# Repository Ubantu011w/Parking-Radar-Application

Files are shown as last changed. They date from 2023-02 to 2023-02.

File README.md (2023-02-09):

# **Parking radar sensor**
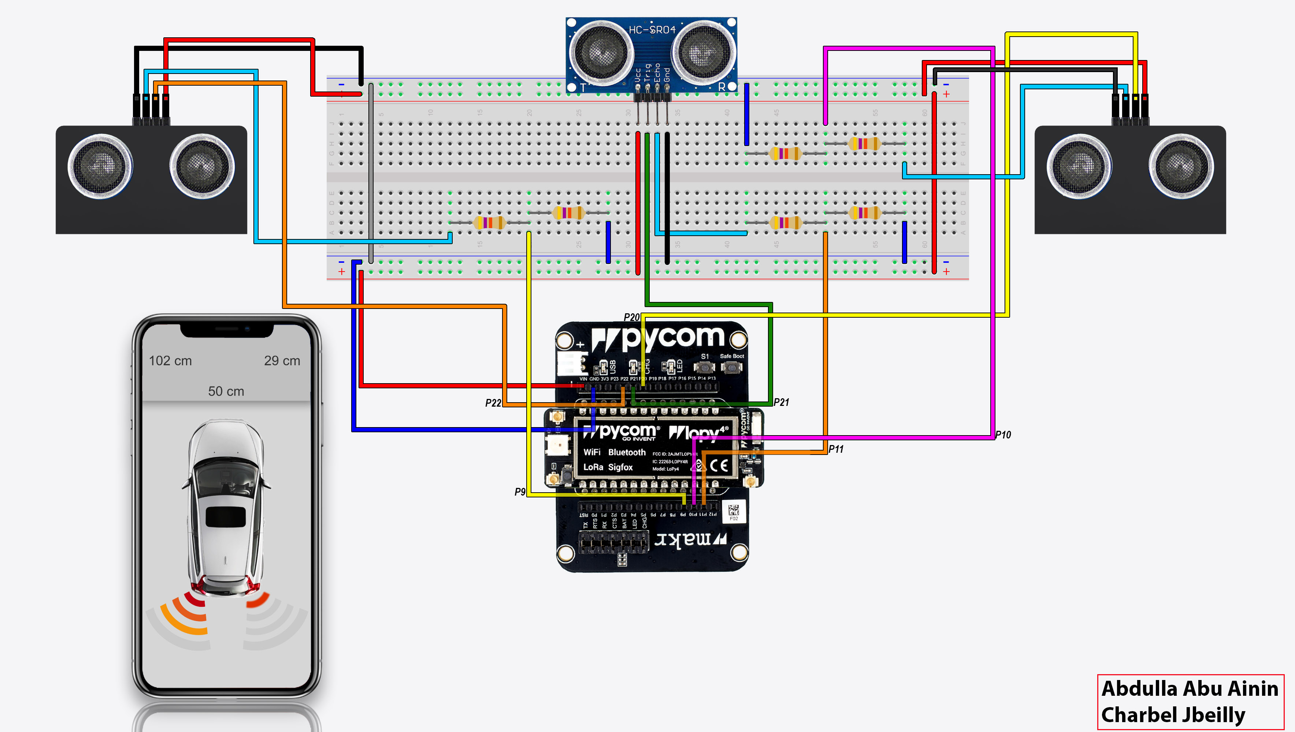
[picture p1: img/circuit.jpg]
Project


* Ladda ner Appen: 
    * Android [Prototype.apk](https://drive.google.com/file/d/1J4INymdXIyaqrTZJNHQ8nDmvR2BSV0AG/view?usp=sharing) 17 MB
    * Windows [Prototype.zip](https://drive.google.com/file/d/10sR1H_vFRUNZAB479mF9K6l9i8I3TnrY/view?usp=sharing) 20 MB

- Bilder [/img](./img/)

# Beskrivning och Bakgrund:
Parking Radar Sensor med Arduino som kommunicerar med en app på android, Radarn är baserad på 3 ultraljud sensorer som upptäcker hinder från 3 olika håll; vänster, höger och mitten.
 Vi har tänkt att sensorerna ska bli ett säkerhetssystem som varnar användaren för kommande hinder. Sensorerna är främst tänkte för bilar. Så att bilen har ett extra skydd som varnar om nära objek/hinder så att man inte ska krocka. Vi bestämde oss för detta projekt för vi tyckte det lät intressant samt en utmaning att ha med tre sensorer istället för en. Vi ska även försvåra arbetet med att göra en applikation som visar värderna från sensorerna. Men allt kommer vara värt det i slutändan.

# Abstract:
Vi började med att bestämma vad vi skulle göra. Vi hade möte med Morgan och fick klartecken att börja jobba. Vi beställde då delar och träffades i biblioteket för att diskutera hur vi skulle gå till väga. Vi jobbade med att konstruera en app som tar emot värden från en mqtt server som tar emot sina värden från kopplingen vi gjorde med tre stycken ultraljud sensorer. Vi använde oss av adafruit för att öppna mqtt server. För appen användes unity och vs code. Och för att få fram current time använde vi atom. Efter varje pass vi arbetade dokumenterade vi i [timelog.md](./doc/timelog.md) vad vi gjorde och hur länge vi jobbade. Vi fortsatte att ha möten med Morgan och fick feedback samt vi diskuterade våra idéer. Slutligen fick vi allting och blir klart. Vi har en fungerande app som tar emot värden från mqtt som tar emot sina värden från våran koppling. Detta är tänkt att fungera som en bilsesnor för att varna användaren om avståndet till objekt/hinder som finns bakom bilen.

# Resultat:
Resultatet blev en app på android som visar värden från  (Parkerings sensorerna) via Mqtt Broker.

## Projektet:

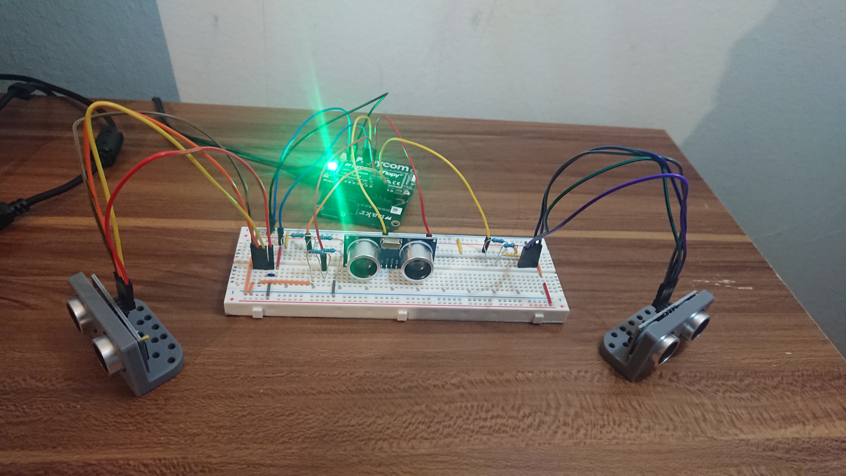
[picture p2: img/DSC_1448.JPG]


## Appen:

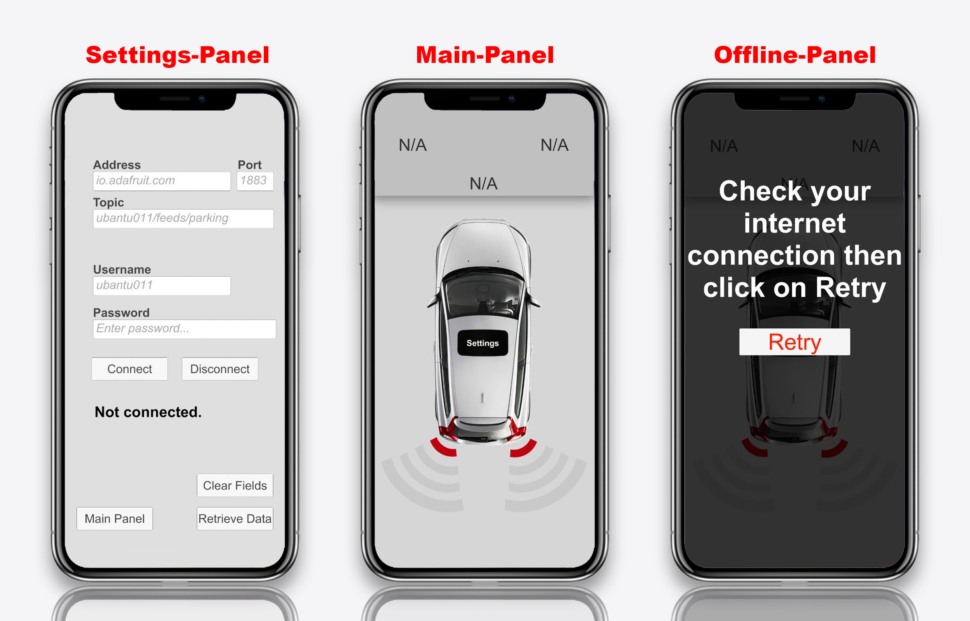
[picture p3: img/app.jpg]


* [/src](./src/)
    * [Project_files](./src/project_files)
    * [App_files](./src/App_files)
---

# Metod:
Filerna med beskrivning:
* [/doc](./doc/)
    * [Hardware.md](./doc/hardware.md)
    * [Setup.md](./doc/setup.md)
    * [Test.md](./doc/test.md)
## Andra filer:
* [/doc](./doc/)
    * [Requirments.md](./doc/requirments.md)
    * [Timelog.md](./doc/timelog.md)
    * [3d Model - Sensor-hållare](./doc/3d_modell)

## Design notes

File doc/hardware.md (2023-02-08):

# Sammanfattning:
Den första sensorn kopplas direkt på breadboard och sladdar dras från pycom till breadboarden så att sensorn får ström. De andra två sensorerna kopplas inte fast i breadboarden utan är mer rörliga så att de går att justera. De två lösa sensorerna kopplas via hon-kablar. Till varje sensor behöver vi 2 resistorer. Och alla är kopplade till GND och VIN. (Kan behövas bild på kopplingen)

## Vi behöver följande:

| st | Item's name | Link |
|----|:---:|:---:|
| 3  | HC-SR04 | [m.nu](https://www.m.nu/sensorer-matinstrument/hc-sr04-ultrasonic-sensor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) |
| 1  | Pycom lopy 4 | [m.nu](https://www.m.nu/pycom/lopy4-with-headers) |
| 1  | Expansion Board 3.1 | [m.nu ](https://www.m.nu/pycom/expansion-board-31)  |
|  3,3  | 1k , 2.2k Resistors | [Amazon.de](https://www.amazon.de/-/en/gp/product/B01M7N4WB6/ref=ppx_yo_dt_b_asin_title_o00_s00?ie=UTF8&psc=1) |
| 1  | breadboard & wiring kit | [Amazon.de](https://www.amazon.de/-/en/gp/product/B01M7N4WB6/ref=ppx_yo_dt_b_asin_title_o00_s00?ie=UTF8&psc=1) |

I HC-SR04 sensorn har vi 4 pins (VCC,TRIG,ECHO,GND). Dessa sensorer behöver 5v så vi kommer att använda VIN pin från Pycom enheten för att använda sensorerna, samtidigt behöver vi minska voltage från 5V till 3,3 för att kunna ansluta den till ECHO då kan vi använda 1 st 1k resistor och 1 st 2.2k resistor för varje sensor.

- Vi börjar först med att koppla lopy4 på expansion boardet:

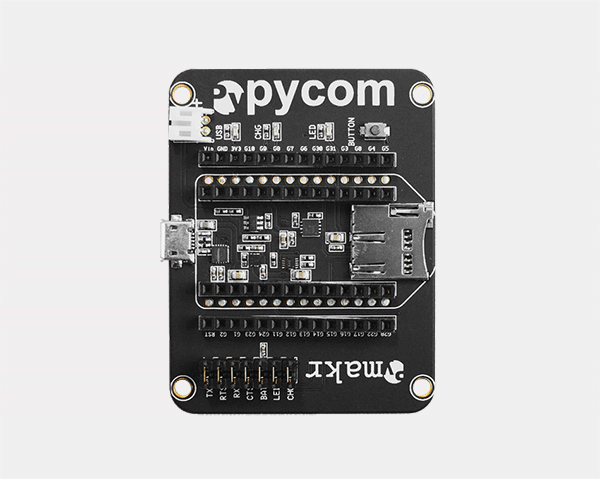
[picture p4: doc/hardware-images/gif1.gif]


- Sen kopplas 1 st 1k resistor och 1 st 2k resistorer i breadboarden och ena sensorn kopplas och ansluts till Pycom på följande sätt: ("s1" för första sensorn)
  - LoPy4 VIN <--> s1.VCC
  - LoPy4 P21 <--> s1.TRIG
  - s1.ECHO <--> 2.2k resistor <--> 1k resistor <--> LoPy4 P11
  - LoPy4 GND <--> s1.GND

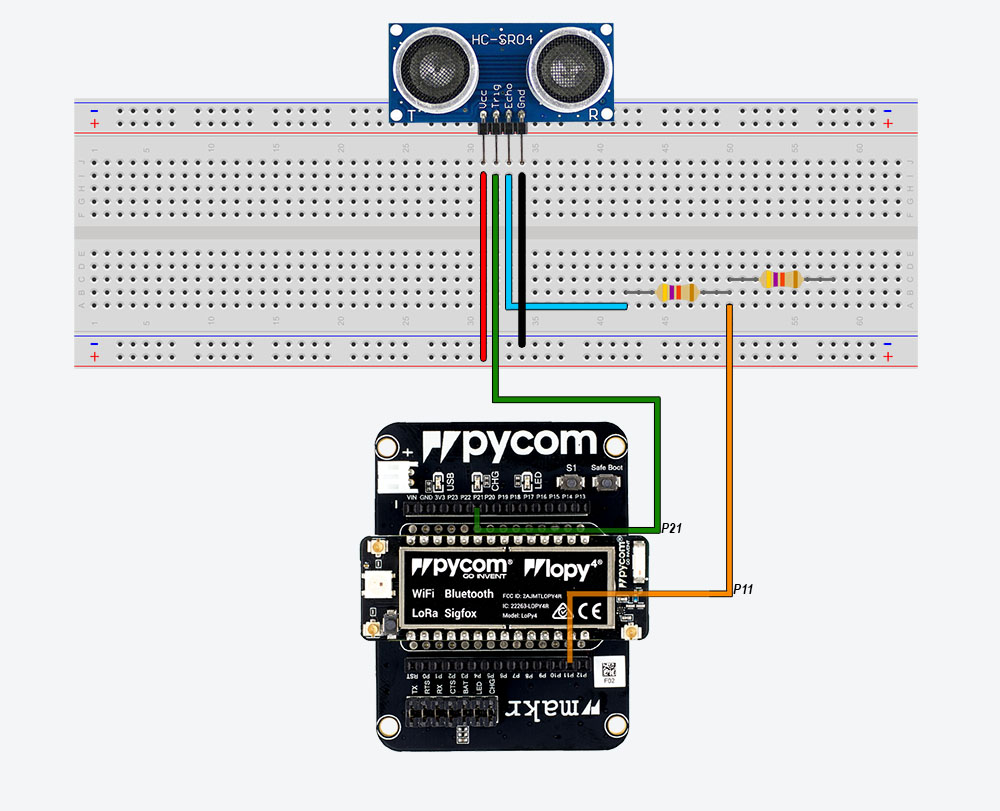
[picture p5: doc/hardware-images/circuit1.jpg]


- Efter det sätter vi de andra 2 sensorerna i våra sensor behållare som vi printat ut för att kunna vrida sensorerna så att vi täcker en större yta.

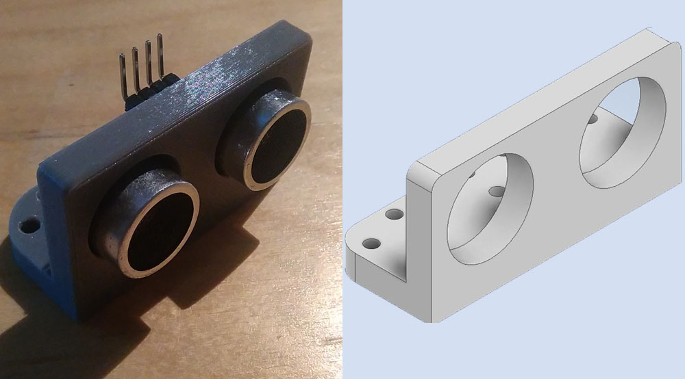
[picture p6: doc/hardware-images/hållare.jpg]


Och vi ansluter de till breadboarden och till Lopy4 via hane-hona kablar på följande sätt: (s2 sensorn till vänster, 's3' sensor till höger)
  - LoPy4 VIN <--> s2.VCC , s3.VCC
  - LoPy4 P21 <--> s2.TRIG
  - LoPy4 P20 <--> s3.TRIG
  - s2.ECHO <--> 2.2k resistor <--> 1k resistor <--> LoPy4 P11
  - s3.ECHO <--> 2.2k resistor <--> 1k resistor <--> LoPy4 P10
  - LoPy4 GND <--> s2.GND, s3.GND

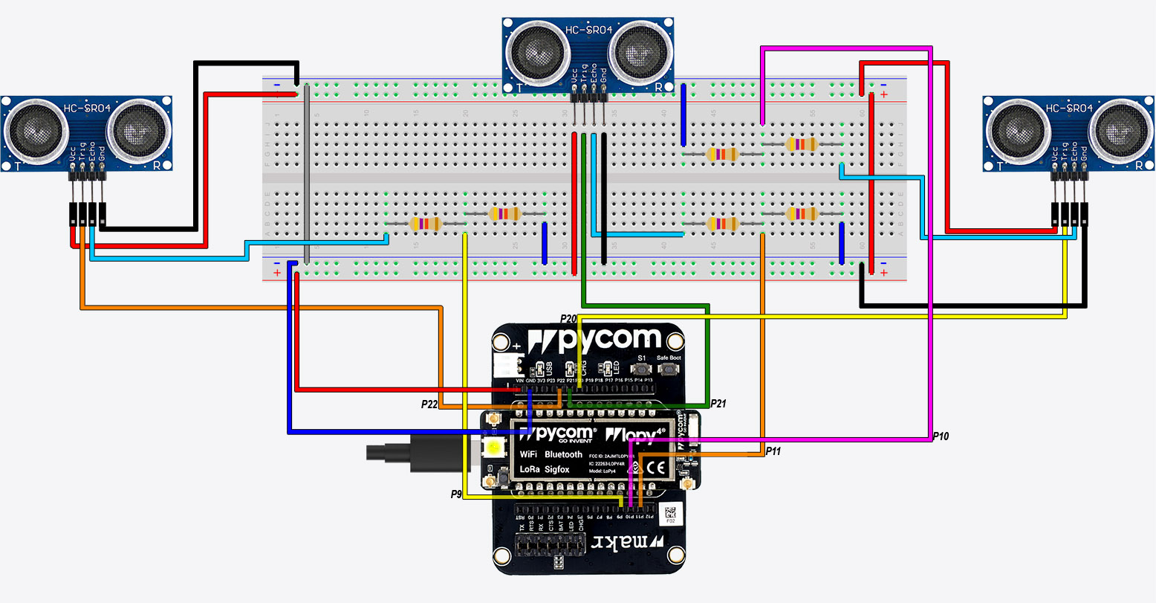
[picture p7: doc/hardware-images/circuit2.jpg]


- Sen kopplar vi enheten till en el uttag som supportar 5 Voltage och då lyser ett grönt ljus på Lopy 4 om vi är kopplade till nätverket utan problem.

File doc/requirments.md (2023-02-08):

Målet är att skapa en parking radar sensor som är uppbyggt på 3 ultrasonic sensorer som kommunicerar med en app via mqtt och varnar oss om avståndet mellan sensorerna och objekten som närmar sig. Sensorerna är tänkta att kunna användas som säkerhetssystem till bilar. Där de varnar om hur nära bakdelen på bilen är ett objekt/hinder.

- Projektet ska uppbyggas på fokus på att undvika äventuella nätverk connection fel.

- Vi kommer inte att använda projektet utomhus för att sensorerna som vi använder är inte vattentätta.

- Då handlar projektet om hur man utför en parkering sensor med arduino och pycom.

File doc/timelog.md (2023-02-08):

- 07/12/2020:    Abdulla och Charbel, Träffades i bioblioteket och testade sensorerna. Vi bestämde att använda en mqtt server.
2 timmar

- 08/12/2020:   Vi har kopplat ihop sakerna. Vi kopplade de tre sensorerna, men de två yttersta sitter inte på breadboard utan de är kopplade via hona-hane kablar så att vi kan rotera dessa efter behov. Mitten sensorn är kopplad direkt på breadboarden. Vi jobbade totalt cirka 1 timme. 

- 10/12/2020: Vi bestämde idag om hur vi skulle skydda sensorerna så att de skulle kunna användas i något område. Vi hittade en sida som 3d printar. Vi ska printa skydd som täcker sensorerna samt håller sensorerna på samma höjd för mer precis data. Vi bestämde även att vi ska bygga appen med hjälp av unity engine. Nästa gång så ska vi börja bygga appen och räkna på ett ungefär hur lång tid det tar att skicka data från sensorerna till appen.

- 12/12/2020: Idag pratade vi lite om hur vi skulle gå tillväga med arbetet. Vi diskuterade även om vilka funktioner appen skulle kunna tänkas ha. Till exempel i appen kan det tänkas finnas ett varningssystem, att appen piper om ett objekt befinner sig på ett specifikt avstånd, eller ha en röst som varnar. Vi hittade även sensor hållare, som hjälper oss att ställa sensorna stadigt på samma höjd utan ovilliga rörelser för en mer precis data. Vi tänkte oss ha med en kamera som visar live video i appen, men det blir nog för mycket samt krångel med koppling. Idag har vi jobbat cirka två timmar.

- 14/12/2020: Idag har vi diskuterat kring appen och kopplingen. Vi hittade en open source kod som vi modifierade som anslöt våran mqtt server till unity. Vi diskuterade också om att vi ska 3d printa sensor hållarna istället för att köpa dem klara från butik. Abdulla gjorde en modellering över våra sensor hållare för att han har mer erfarenhet i modelleringsprogram. Charbel kontaktade en kompis som kan hjälpa oss att printa. Abdulla designade två modeller. En modell är skyddad och den andra är oskyddad. Vårt totala arbete idag är cirka fyra timmar.

- 15/12/2020: Idag jobbade Abdulla med konstruktion av appen, och Charbel jobbade med att få fram aktuell tid som vi ska använda i appen. Charbel är inte riktigt klar än men förhoppningsvis snart.

- 16/12/20: idag har vi testat första prototypen för appen och jobbade med UI-element vi har inte räknat hur mycket tid tar det exakt att få data från sensorerna till appen men som det ser ut så tar det ungefär 0.5 sekunder. Nästa gång ska vi jobba med backenden. Abdulla 3 timmar. Charbel fortsätter jobba med att få fram aktuell tid.

- 17/12 Jobbade Charbel med att räkna tiden i Pycom genom att synca tiden med en ntc server och Fick hjälp av Fredrik. Charbel 4 timmar

- 18/12 Jobbade Abdulla med att räkna tiden som behövs för att få data från Pycom till Appen. Och vi blev klara. Sen jobbade Abdulla med UI i appen. Abdulla ca 4 timmar.

- 19/12 Programmering och beställde 2st utskrifter av sensor hållare. Gjorde en Circuit design och laddade upp den till /doc. Abdulla 4 timmar.

- 21/12/2020: Idag jobbade Charbel med att programmera så att vi kan föra över de olika distanserna som läses av sensorerna till mqtt servern. Så att de senare kan tolkas vidare i appen. Jag jobbade cirka 2 timmar med detta.

- 25/12/2020 Idag jobbade Abdulla med att färdiggöra projektet; testat att köra det 2 timmar utan problem, ändrat lite i koden och i kopplingen så att den ser enklare ut (Ny bild i /img) appen är nästan färdig och det är bara sista issuen (Ui scripting) som är kvar. jobbat 6 timmar.

- 28/12 Abdulla, jobbade med appen och löste ui-scripting issue, skapat Circuit ritning som ska användas i rapporten/presentation. 8 timmar.

- 30/12/2020 Charbel jobbade med att uppdatera alla filer med ny information. Det skrevs om hur vi testade, kopplade och massa annat. Det är lite mer finjustering som måste ske innan allt är helt klart. Har jobbat cirka 2 timmar 

- 2/1/21 Abdulla, jobbade med att färdiggöra koden och appen. Började ta bilder som ska användas under presentationen. 6 timmar.

- 11/1/21 Abdulla, Skapade en ny panel Settings där man kan mata in Mqtt uppgifterna, grejat med setup.md. Totalt 9 timmar.

- 13/1/21 Abdulla och Charbel har skrivit färdigt alla filer i /doc och de är redo för att lämnas in, har bara presentationen kvar att göra. 5 timmar.

15-1-21 Abdulla och Charbel jobbade med presentationen. Abdulla 8 timmar, Charbel 4 timmar

Charbel - Jobbat cirka 49 timmar
Abdulla - Jobbat cirka 68 timmar
Tillsammans - Cirka 117 timmar

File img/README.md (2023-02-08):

## Projektet:



---
## Appen:



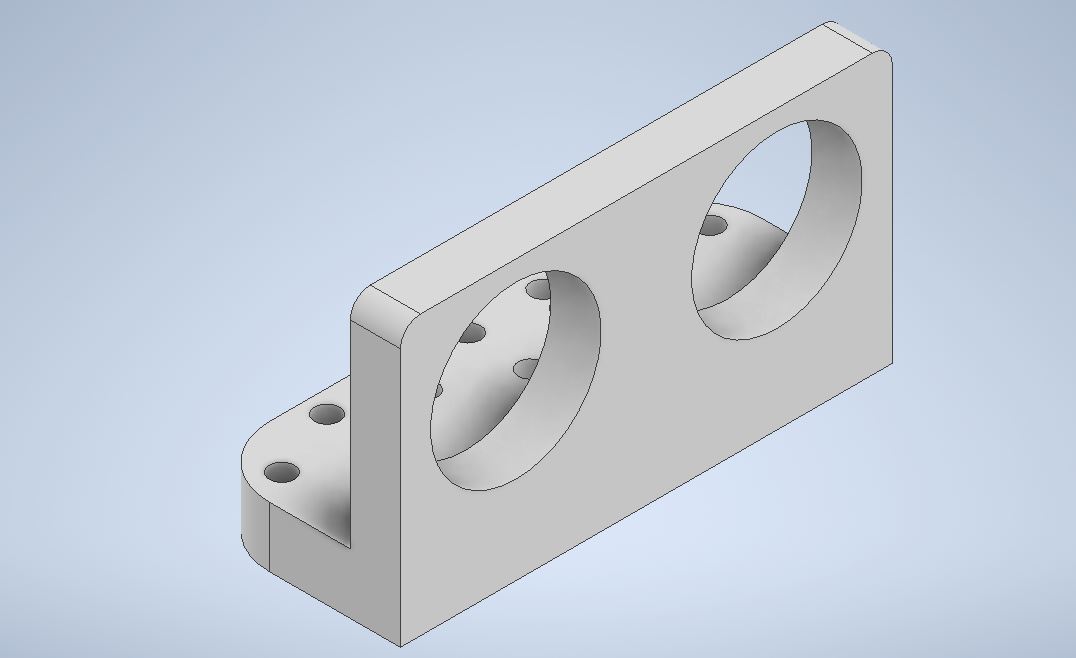
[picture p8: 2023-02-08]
doc/3d_modell/capture.JPG

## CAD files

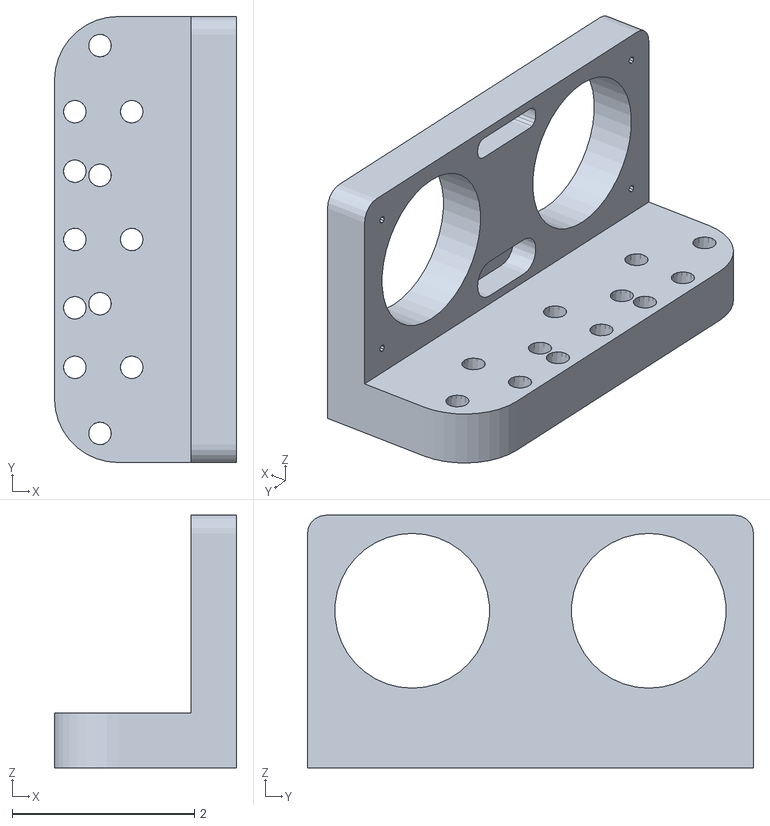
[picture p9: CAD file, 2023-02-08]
doc/3d_modell/stl.stl
2.00 x 4.90 x 2.78

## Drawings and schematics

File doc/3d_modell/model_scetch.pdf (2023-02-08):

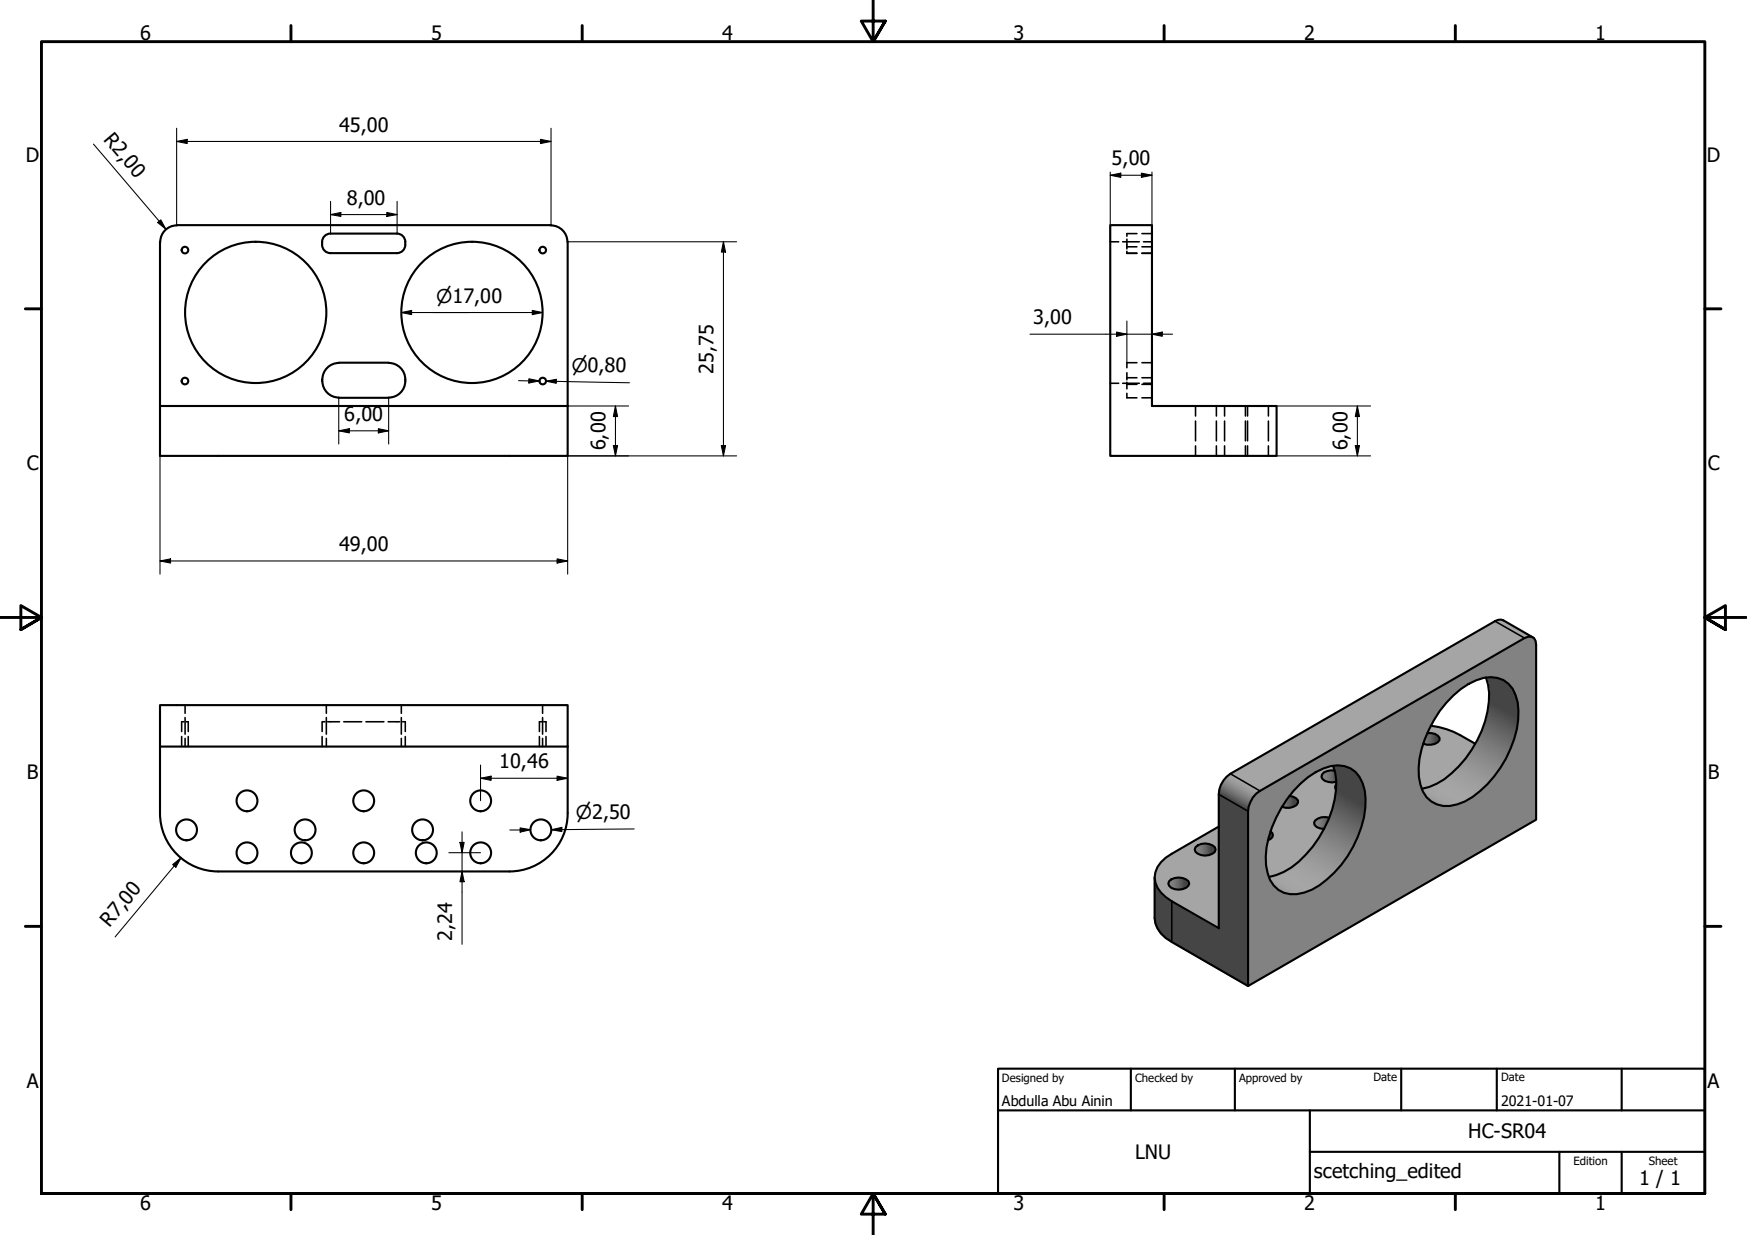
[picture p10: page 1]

Designed by Abdulla Abu Ainin | Checked by | Approved by Date | Date 2021-01-07

LNU | HC-SR04

scetching_edited | Edition | Sheet 1 / 1

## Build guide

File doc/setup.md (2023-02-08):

# Sammanfattning:
Vi använde atom, unity, Visual studio code och adafruit. Vi använde atom för att skriva fram kod som tar fram de olika värden från sensorerna, och skicka dessa till Adafruit via MQTT. Adafruit använde vi för att öppna en mqtt server där data togs emot från sensorerna som sedan skickas till appen. Unity är en engine som vi använde för att konstruera appen. Det användes också Visual studio code för att skriva kod i unity. Så slutprodukten blir sensorer som skickar avståndet från ett objekt till en mqtt server som senare skickas vidare till en app som 

## Projektet (Pycom ---> Adafruit):
Först så behöver vi koppla oss till Wifi för att kunna skicka data till Adafruit via Mqtt. Via koden: [wifi.py](https://gitlab.lnu.se/1dt308/student/team-14/-/blob/master/src/project_files/wifi.py)

Sen tar vi in distanser från sensorerna, Ultrasonic sensorer räknar tiden i millisekunder och ljud hastigheten är 340m/s eller .034cm/us. Och vi vet att vi behöver dela tiden vi får med _2_ på grund av att sensoren räknar tiden som behövs för pulsen att resa fram och tillbaka.
Då får vi formeln:
`Distance = (Time(us) * .034) / 2` .

Och vi samlar alla 3 distanser i en string och och avnänder ";" så vi kan skilja ut de i appen sen.
``` python  
string = distance + distance2 + distance3 # string = "0;0;0";
``` 
 Sen skickas de till Adafruit. Vi prenumererade på Adafruit-Plus för att kunna utnyttja maximala antal data points. och det är **60 data points per minut** vilket innebär att vi måste vänta en sekund för att skicka ett nytt värde till Adafruit. 
 
 Kod i Python: [main.py](https://gitlab.lnu.se/1dt308/student/team-14/-/blob/master/src/project_files/main.py)

**Resultatet:**

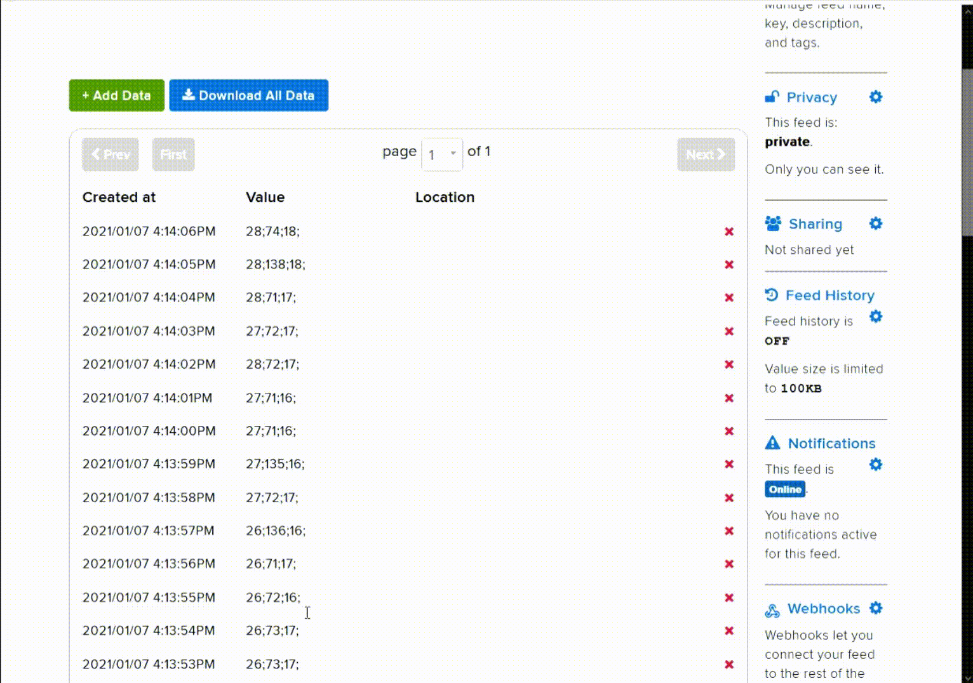
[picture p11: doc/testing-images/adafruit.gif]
Adafruit


## Appen (Adafruit ---> Unity):

Unity är faktiskt en spel engine där det är jätte lätt att skapa en prototyp app för Android eller IOS.
Och vi hade tur att det finns ett färdig open source projekt på nätet som tolkar Mqtt connection till Unity [link](https://github.com/eclipse/paho.mqtt.m2mqtt) så vi behövde bara ändra i källkoden så att användaren kan mata in Mqtt uppgifterna (address, port, username, password, topic-address) I en "settings panel". 

Se hela koden med kommentarerna. [här](https://gitlab.lnu.se/1dt308/student/team-14/-/blob/master/src/App_files/Mqtt_to_unity.cs) 

Bild på Settings-panel:

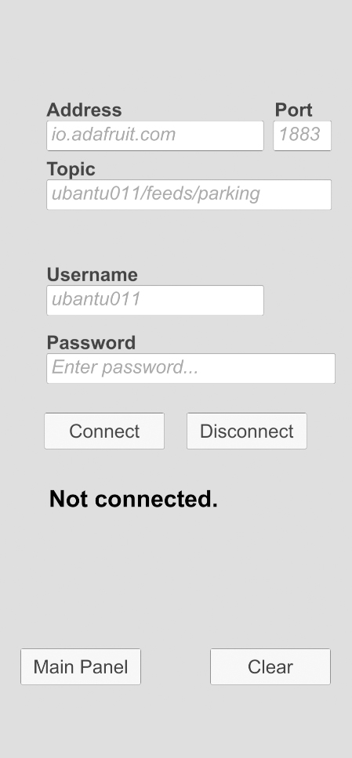
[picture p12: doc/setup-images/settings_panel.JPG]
settings-panel


Efter det behövde vi ta in stringen som skickas från Pycom och dela ut den till 3 variabler, (distance_middle, distance_right och distance_left).

Kod i csharp: [Mqtt_to_unity.cs](https://gitlab.lnu.se/1dt308/student/team-14/-/blob/master/src/App_files/Mqtt_to_unity.cs)
``` csharp 
private void ProcessMessage(string msg)
{
string[] distances = {"0"};
string divide="";

foreach (char c in msg)
{

    if (c.ToString()==";")
    {
        if (distances[0]=="0")
        {
            distances[0]=divide;
            distance1_int= int.Parse(divide);           // int (distans) ska användas i ui-scripting.cs för att animira radarerna.
            if (distance1_int<=250)
            {
                distance1.text=distances[0] + " cm"; //distance1.text är en text field som vi ser i skärmen. (se figuren(2))
            }
            else
            {
                distance1.text=">250";
            }
            divide="";
        }
    }
    else
    {
     divide+=c;
    }
}
```

Bild på Main-panel med kommentar:

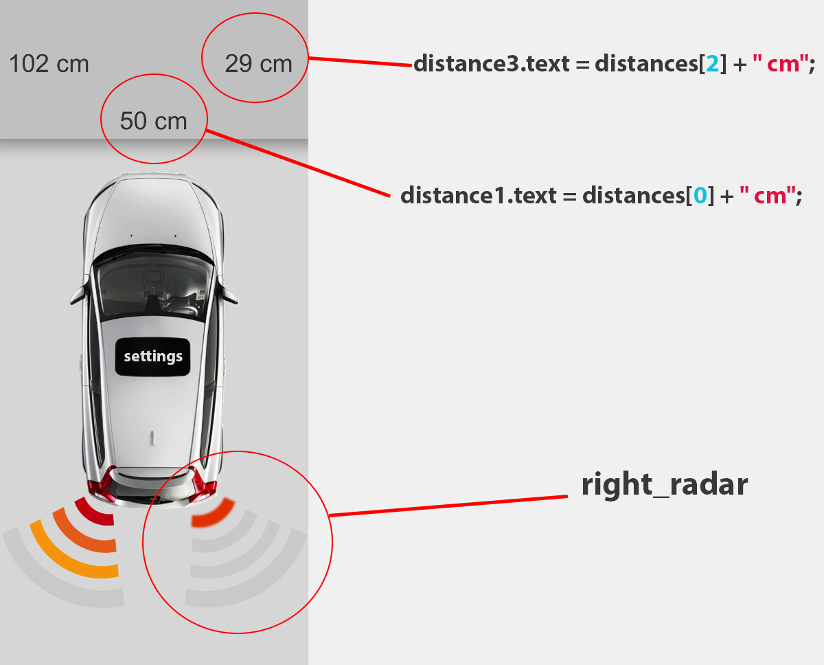
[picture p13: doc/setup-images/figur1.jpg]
Figur1


Efter det animerade vi 2 radarer som rör sig beroende på värdena från sensorna.
De har 4 steg.

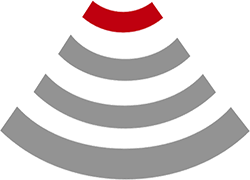
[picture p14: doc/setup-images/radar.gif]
radar

- **Rött** lyser när avståndet är mindre 30 cm.
- **Orange** lyser när avståndet är mindre än 75 men större än 30 cm.
- **Gul**; lyser när avståndet är mindre än 150 cm och större än 75 cm.
- **Grönt**; lyser när avståndet är större än 150 cm.

På grund av att vi har 3 sensorer och bara 2 radarer. Så bestämdes det att göra sensoren i mitten till "Main Sensor" det innebär att om värdet på denna sensor är mindre än de andra 2 sensorerna, då ska värdet på den bestämma över animationen på de 2 radarer. Se koden med kommentarer:

Kod i csharp: [UI_scripting.cs](https://gitlab.lnu.se/1dt308/student/team-14/-/blob/master/src/App_files/UI_scripting.cs)
``` csharp 
    IEnumerator comparing()
    {
        M2MqttUnityTest M2MqttUnityTest = this.GetComponent<M2MqttUnityTest>(); /*importerar scripten "M2MqttUnityTest.cs"
                                                                                    med alla värden i.*/
        yield return new WaitForSeconds(0.01F);             /*Vi behöver lägga den här för att det tar några millisekunder
                                                         att få värden från sensorerna till appen.*/
        string objectname;
        int distance_middle = M2MqttUnityTest.distance1_int;           // Importerar distans värdet från sensorn i mitten 'här;0;0;'
        int distance_left = M2MqttUnityTest.distance3_int;              //0;0;här;
        int distance_right = M2MqttUnityTest.distance2_int;             //0;här;0;

        if (distance_middle<= distance_left && distance_middle<= distance_right) /* Vi jämför mellan distanserna och om värdet 
                                                                                från mitten sensorn är mindre än de andra då 
                                                                                kör vi följande funktionen som påverkar 
                                                                                både höger och vänster radars.*/
        {
            objectname="left_radar";
            radar_animation(distance_middle,objectname);
            objectname="right_radar";
            radar_animation(distance_middle,objectname);
        }
        else 
        {
            objectname="left_radar";
            radar_animation(distance_left,objectname);
            objectname="right_radar";
            radar_animation(distance_right,objectname);
        }
    }

    private void radar_animation(int distance, string objectname)  // funktionen ändrar animation på högra radarn.  
    {                                               
            radar = GameObject.Find(objectname);            //GameObject.Find(string) hittar objekt via dess namn.
            if (distance>=150)                         // om avståndet mellan hinder och sensorn större än 150 cm
                                                       // då 'lyser' alla färgerna på radarn.
            {
                radar.GetComponent<Animator>().Play("full");
            }

            else if (150>distance && distance>=75)
            {
                radar.GetComponent<Animator>().Play("orange");
            }

            else if (75>distance && distance>=30)
            {
                radar.GetComponent<Animator>().Play("dark_orange");
            }

            else if (distance<30)
            {
                radar.GetComponent<Animator>().Play("red");
            }
     }
``` 
## Undvika fel i Pycom & Appen:

för att undvika eventuella anslutnings fel från Pycom enheten har vi lagt in följande i en While loop:

Kod i Python: [main.py](https://gitlab.lnu.se/1dt308/student/team-14/-/blob/master/src/project_files/main.py)
``` python

while True:
    # Checking connection.
    if not wlan.isconnected():
        connect_wifi()
    elif adafruit_connected==False:     #Global variabel som blir True om man kör adafruit_connect()
        adafruit_connect()

``` 
---
Och för att undvika samma problem i Appen har vi skrivit en kod som kollar nätverksanslutning varje millisekund, och om vi inte är anslutna så dyker en panel upp med knappen "Retry" som kör funktionen restart() (se koden ner) och då laddas allt om och kollat återigen om vi är anslutna.

Kod i csharp: [check_connection.cs](https://gitlab.lnu.se/1dt308/student/team-14/-/blob/master/src/App_files/check_connection.cs)
``` csharp
//Kollar network connection varje sekund.
yield return new WaitForSeconds(1);
if (Application.internetReachability == NetworkReachability.NotReachable)
        {
            offlinepanel.SetActive(true); // Detta Gör en panel "Offline_Panel" visible om det finns ingen connection.
        }

```

Bild på Offline Panel:

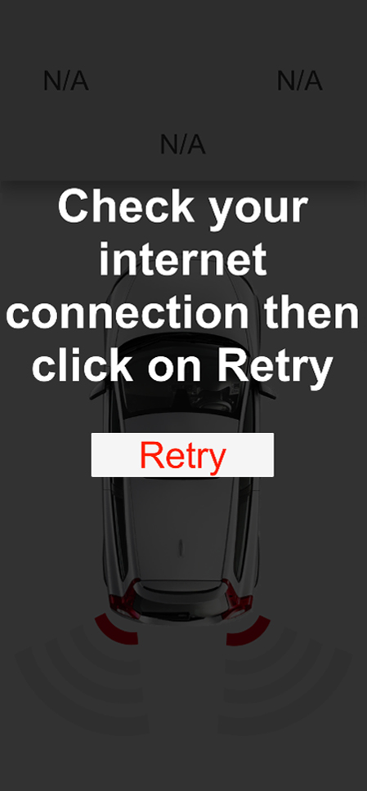
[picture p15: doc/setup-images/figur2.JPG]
figur2


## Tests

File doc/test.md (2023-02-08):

# Sammanfattning:
Kopplingen var rätt enkel. Men sensorerna testades en gång i taget för att se om vi fick individuella värden. När det funkade så testades alla sensorer samtidigt. Det uppstod ett problem som vi även skrivit in i en [issue](https://gitlab.lnu.se/1dt308/student/team-14/-/issues/1) på gitlab. Det är att pycom kopplas från atom för att det är för hög strömförbrukning. Lösningen på detta var att koppla bort GND när vi skulle ladda upp ny kod till pycom. Och sen ansluta till en strömkälla som klarar av 5V och även koppla upp till mqtt servern för att få resultatet.

## Att testa sensorerna:
Vi testat sesorerna genom att hålla en objekt och röra den runt och se vilka resultat vi får med det.

För hållbarhetens skull har vi testat att hålla Pycom enheten på i 2 timmar, och den fungerade som den ska med appen och sensorerna.

Resultatet på Adafruit feed:

adafruit

## Att testa appen:
Det går att testa appen genom att ladda ner den till en android enhet [prototype.apk](https://drive.google.com/file/d/1bIwu2aPql3wvMc3xpz3gCrHTkoWRGxV1/view?usp=sharing) eller windows [prototype.zip](https://drive.google.com/file/d/10sR1H_vFRUNZAB479mF9K6l9i8I3TnrY/view?usp=sharing) och testa funktionerna i den som till example att koppla den till en Mqtt server och skicka en string till den som innehåller 3 integraler på sådant sätt: ("0;0;0;") och se hur radarerna reagerar.

Exempel på result:

radars

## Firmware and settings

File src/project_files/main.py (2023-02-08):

import time
from machine import Timer
from machine import Pin,PWM
from mqtt import MQTTClient
import network
import pycom
from wifi import *

adafruit_connected=False
pycom.heartbeat(False)

# Connecting to Mqtt
def adafruit_connect():
    global client, adafruit_connected
    client = MQTTClient("Charbel", "io.adafruit.com",user="ubantu011",password="aio_btUr85N6wp5RGRCgGfnkV8poj1pr", port=1883)
    client.connect()
    adafruit_connected=True

# Getting distance from a certain sensor
def get_distance(echo,trigger):
    chrono = Timer.Chrono()     # Chrono() räknar time spans.

    chrono.reset()

    trigger(1)
    time.sleep_us(10)
    trigger(0)

    while echo() == 0:
        pass

    chrono.start()

    while echo() == 1:
        pass

    chrono.stop()
    distance = (chrono.read_us() * .034) /2 # (Time(us) * .034) / 2, ljudhastighet / 2
    return str(int(distance)) + ";"     # Returning a string so it can be added up to one variable "string"
                                        # and send it to Adafruit.


# Initialise Ultrasonic sensors pins
echo = Pin('P11', mode=Pin.IN)
trigger = Pin('P21', mode=Pin.OUT)

echo2 = Pin('P10', mode=Pin.IN)
trigger2= Pin('P20', mode=Pin.OUT)

echo3 = Pin('P9', mode=Pin.IN)
trigger3= Pin('P22', mode=Pin.OUT)

connect_wifi()
adafruit_connect()

trigger(0)
trigger2(0)
trigger3(0)


while True:
    # Checking connection.
    if not wlan.isconnected():
        connect_wifi()
    elif adafruit_connected==False:
        adafruit_connect()

    distance = get_distance(echo,trigger)
    distance2 = get_distance(echo2,trigger2)
    distance3 = get_distance(echo3,trigger3)

    string = distance + distance2 + distance3        # Gathering all data into one string.

    client.publish(topic="ubantu011/feeds/parking", msg=string) # Sending the string.

    time.sleep(1)                   # We wait a whole second because data points to
                                    #adafruit are limited by 60 datapoints per minute.
